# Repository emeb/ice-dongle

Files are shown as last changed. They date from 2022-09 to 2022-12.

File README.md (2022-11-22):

# ice-dongle
USB-C Dongle with ice40 UP5k FPGA

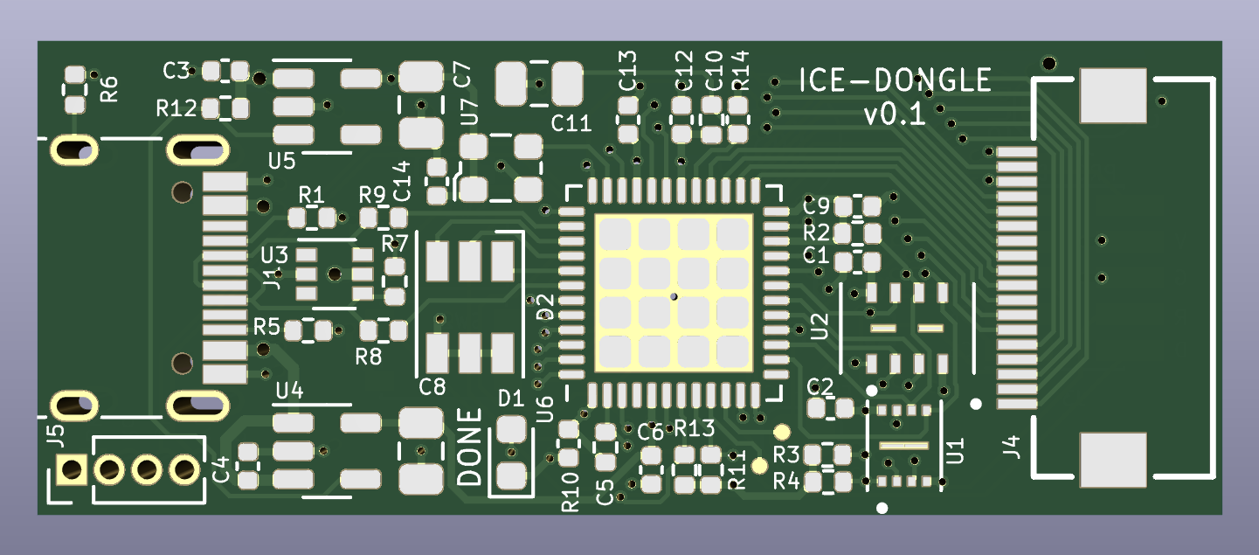
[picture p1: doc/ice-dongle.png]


## Abstract
This is a small USB connected FPGA board in a "dongle" form-factor. Note that
it's not a true dongle since it doesn't have a USB plug (USB-C plugs are not
practical for DIY assembly at the time this was designed) - instead it has a
USB-C jack and you can use an inexpensive M-M adapter to achieve dongle-like
function.

For I/O it provides an 18-pin FPC connector that conforms to the Eye-SPI
standard found on some Adafruit products. This standard includes 3.3V power
as well as 16 GPIO for things like SPI or I2C device, most often TFT LCD
displays and user interfaces.

The FPGA is directly connected to USB and is pinned-out similarly to the
1bitsquared Icebreaker Bitsy so the NO2FPGA bootloader and user designs for
that ecosystem should port over with minimal changes. It includes 8MB of flash
and 8MB of PSRAM, as well as an RGB LED and a user button.

Initial programming of the FPGA bitstream takes place through a 1.27mm SMD
header footprint on the back of the board. The original intent was to access
this temporarily via the Adafruit "Pogo Pin Probe Clip" which should have
attached easily over the pads. Unfortunately the pogo pin row spacing is too
narrow for the SMT header pads so I ended up soldering on a header and using
a normal cable. This may be fixed in future revisions, but for now an actual
header + cable is probably more reliable for long-term development.

## Status
### 22-10-15
Boards are back from OSHpark and so far things are working.
* USB power, regulators and clock oscillator are running properly.
  * Minor silkscreen error was discovered - reference designators for R14 and C10 swapped.
* FPGA configures via programming header and from SPI flash.
* SPI flash can be written from the programming header.
* RGB LED works.
* EYESPI bus works with ST7789 TFT LCD
* PSRAM works.

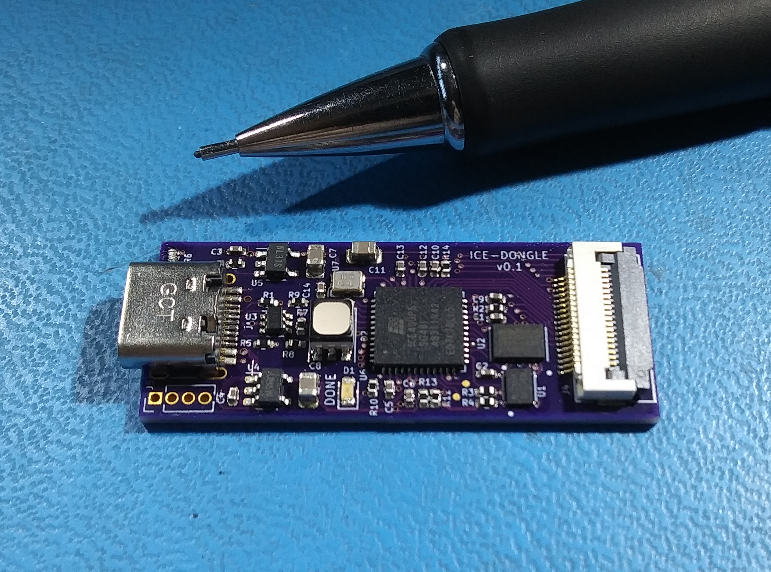
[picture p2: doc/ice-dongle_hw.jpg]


### 22-10-16
USB FS interface is fully functional with the NO2 Bootloader. I've forked it to
add a custom BOARD target for ice-dongle but I'll submit a PR to the main project
when things settle down a bit. For the time being here's my fork:

[NO2 Bootloader](https://github.com/emeb/no2bootloader)

To build, clone that and follow the directions in the README. A few additional
notes:
* Don't forget to `git submodule update --init` to get all the related material
from the NO2 ecosystem.
* To build use `make BOARD=ice-dongle bootloader`
* The `riscv_lcd` gateware project has a `make dfu` target that shows how to use
the bootloader.

### 22-10-17
Ordered some helper boards to make interfacing easier:
* ice-fpc-pmod
* ice-prog-adapt

find out more about them in the [Hardware](Hardware) directory.

### 22-11-20
* Sylvain Munaut (@tnt) has built up a couple ice-dongle boards and confirmed that
they work outside my lab. He did spot another silkscreen error - R10 and C5 reference
designators are swapped. This doesn't significantly affect the board operation but
should be corrected.
* Updated NO2 board definition to put serial pins on programming
header and sent a PR which has been accepted. You can now use the mainline
NO2 bootloader repo instead of my fork.
* Added a LiteX gateware design. This works but even a minimal demo uses > 80% of
the FPGA resources.

### 22-11-21
Corrected silkscreen errors and bumped revision to V0.1a

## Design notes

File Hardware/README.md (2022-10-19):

# ice-dongle Hardware
These are kicad projects for the ice-dongle board.

## ice-dongle
the main board design for the ice-dongle



## ice-fpc-pmod
a simple FPC to dual PMOD breakout board. Note that this can be
used for both FPC -> PMOD socket as well as PMOD pin header -> FPC just by
flipping the board upside down.



## ice-prog-adapt
breaks out the 10-pin 1.27mm IDC header to 2.54mm single-row
pins for connection to a programmer and UART.



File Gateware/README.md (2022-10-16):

# ice-dongle Gateware
These are various FPGA gateware projects for the ice-dongle board. Everything here
uses the open-source FPGA tools available here:

https://github.com/YosysHQ/oss-cad-suite-build

The RISC-V firmware build requires a `riscv-64-unknown-elf` toolchain. You can
use the one that's available from the SiFive github:

https://github.com/sifive/freedom-tools/releases

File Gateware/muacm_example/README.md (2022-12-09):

ICE-Dongle ACM + 6502 project
=============================

This project is a combination of Sylvain Munaut's Nitro μACM Example
with a small 65c02 CPU system. I'll be fleshing it out further but for
now it's just a processor, RAM, ROM, 8-bit GPIO and a serial port interface
to the muacm core.

The rest of this documentation is from the muacm repo...

Nitro μACM Example skeleton project
===================================

This project is a small skeleton example of using the Nitro μACM
as a pre-built module. You can use it as a base skeleton for your
own project.

Project infos:
--------------

This project tries to be fairly simple while still illustrating
the points that a user of the μACM module are likely to encounter.

It implements a simple data loopback through a FIFO that lives in
a clock domain distinct from the USB clock domain.

It just instanciates the `muacm` pre-built module, feeds the
required 48 MHz clock in and associated reset signal and wires
up the USB signals to the right pads.

The data interface is then "crossed" over using a pair of special
companion blocks `muacm_xclk` that can be used to cross the clock
domain boundary from the USB domain into any other clock domain
as required by the user application.

Nitro μACM core:
----------------

For details about the core itself and its interface, please
refer to the top level `README.md`.

If you're using the example binary distribution package, then
this should be available here as `README-core.md`.

Clocking Infos:
---------------

The μACM core itself is required to run at 48 MHz to operate
properly (USB is 12 MBits and we use 4x oversampling for clock
recovery).

In this project the 48 MHz clock can come from 2 sources depending
on the `HFOSC` define at the top of `top.v`:

 - Either it comes from the PLL where its generated appropriately
   depending on whatever crystal/oscillator is attached to the
   board (e.g. 48 MHz for the `fomu` or 12 MHz for the `bitsy`).
   The advantage of this approach is a high clock quality and
   precision, but it also uses the PLL which is a precious
   resource that might be needed to generate some other frequency
   in the design.
   In this particular design we generate both 48 MHz ("USB clock")
   and 24 MHz ("User clock") from the PLL but that might not be
   an option in your design.

 - The other option (only in `UP5k`) is to use the `SB_HFOSC`
   block which provides a 48 MHz internal oscillator.
   The advantage is that the PLL remains free and can be used
   to generate any frequency that the user needs.
   The downside is that technically the oscillator is not precise
   enough for the USB spec. I haven't seen any instances where this
   has causes any issue but YMMV.

The data interface out of the blocck is synchronous to the USB
clock. If you need to pass data back/forth a custom user clock
domain, it's recommended to make use of the companion blocks
`muacm_xclk` provided in this repo, or to use asynchronous FIFOs.

The `muacm_xclk` is not very performant but is still good enough
to not cause much penatly if a minimal amount of buffering is
provided on the user side.

Options:
--------

There are a few options that can be enabled / disabled with defines
at the beginning of `top.v` or by changing some `localparam` :

 - `WITH_FIFO`: Add a tiny FIFO in the loopback path, running in the
   user clock domain. This helps efficiency.

 - `WITH_BUTTON`: This makes uses of a small `dfu_helper.v` block
   that connects to the button on the board (if available) and
   it allows to manually reboot into the bootloader when executing
   a long press on the button.

 - `HFOSC`: See 'Clocking' section above.

 - `BOOT_IMAGE`: By default when receiving a `DFU_DETACH` request,
   this will reboot to `WARMBOOT` image `0b01` which is correct
   if you're using the `no2bootloader`. However if using `foboot`,
   it lives in image `0b00` and so that's what should be selected
   to trigger a reboot to `foboot`.

Build:
------

To build:

```
make BOARD=bitsy-v1
```

To program via DFU (assuming a DFU bootloader is already loaded):

```
make BOARD=bitsy-v1 prog
```

Supported boards:

  - `bitsy-v0`: iCEbreaker bitsy rev 0.x
  - `bitsy-v1`: iCEbreaker bitsy rev 1.x
  - `fomu-hacker`: FOMU hacker board
  - `fomu-pvt1`: FOMU production board
  - `tinyfpga-bx`: TinyFPGA-BX board

Make sure to run `make clean` between changing board configuration
since simply changing the `BOARD` variable will not trigger a rebuild.

Board specific notes
--------------------

### 1BitSquared iCEBreaker Bitsy

Those boards are probably the best supported and since they ship with
`no2bootloader` as the main way of loading firmware onto them will
integrate nicely with this project.

### FOMU using `fooboot`

`foboot` is a DFU bootloader so it integrates pretty well with the
DFU runtime provided by `muacm` if you set the `BOOT_IMAGE` to `0b00`
(which is the slot where `foboot` resides). Note that on power up
`foboot` always starts by default and you need to explicitely start
the user bitstream using `dfu-util -e`.

For the `fomu`, since there is no physical button, what is used is
the IO pad 1 and can be 'pressed' by shorting it to ground (for instance
by using tweezers).

### FOMU using `no2bootloader`

If you have replaced the bootloader on your FOMU with `no2bootloader`
instead, then the notes above regarding the `BOOT_IMAGE` settings don't
apply.

### TinyFPGA-BX

This board is using the `iCE40 LP8k` and as such doesn't have an internal
48 MHz oscillator. You must make sure the `HFOSC` option is not selected.

Also, the only button present on this board is directly wired to the
fpga reset pin and is not accessible to the user, so the `WITH_BUTTON`
must also be disabled.

The default bootloader that ships from the vendor with this board is
the _TinyFPGA-Bootloader_ which is not a DFU bootloader. `muacm` will
still expose a DFU runtime interface and you can use `dfu-util -e` to
programmatically reset the board back to the bootloader if you
properly set `BOOT_IMAGE` to `0b00` but you will need to use `tinyprog`
to actually flash a bitstream.

Finally, the _TinyFPGA-Bootloader_ always boots first when plugging
the board into a USB port and will only boot the user bitstream if
either a new bitstream was just programmed, or by using `tinyprog -b`.
Refer to the board manual for more information about its bootloader
operations.

License
-------

 Everything included here is under permissive licenses.

 - The example verilog is under CERN-OHL-P-2.0

 - The bundled pre-built μACM core is a mix between CERN-OHL-P-2.0 and
   ISC (the latter being for the included SERV core). It also contains
   a firmware licensed under MIT.

 All the details can be found in the Nitro μACM git repository
 ( https://github.com/no2fpga/no2muacm ) but from a practical user stand
 point, the only thing required when using this core is attribution to :

 - Nitro FPGA project ( Sylvain Munaut - https://github.com/no2fpga/ )
 - SERV ( Olof Kindgren - https://github.com/olofk/serv )

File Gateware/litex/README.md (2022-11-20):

# ice-dongle LiteX
This builds a minimal LiteX bare-metal demo.

## Building and installing
Install Litex - go here for instructions:
[Litex Github](https://github.com/enjoy-digital/litex)

Put the ice-dongle in DFU mode:
* Press and hold `Boot` button.
* Press and release `RST` button.
* Release `Boot` button.

The RGB LED should by beating a slow cyan color indicating that the DFU
bootloader is ready.

Run the build script
```
./ice-dongle.py --build --flash
```
This will run for a few minutes to build and flash the LiteX demo design onto the
ice-dongle. After it completes you should be able to start up a serial terminal
and communicate with the LiteX command line. Try typing `help` to get started.

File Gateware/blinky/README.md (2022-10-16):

# ice-dongle Blinky
This is a simple RGB LED driver that's used to test the device immediately after
assembly just to make sure basic stuff is working.

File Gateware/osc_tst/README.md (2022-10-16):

# ice-dongle osc_tst
This is a quick test to check out the operation of the on-board 12MHz oscillator
and the FPGA on-chip PLL.

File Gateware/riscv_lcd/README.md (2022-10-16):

# ice-dongle riscv_lcd
This is a RISC-V system with UART, 2 x SPI and I2C used to check out the EYE-SPI
bus and test the SPI PSRAM and Flash interfaces.

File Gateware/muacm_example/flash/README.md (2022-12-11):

Flash data
==========
This directory contains the raw 8KB BASIC ROM contents that is written at
location 0xA0000 in the SPI Flash memory and loaded into SPRAM at run time.

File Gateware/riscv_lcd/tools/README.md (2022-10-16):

#riscv_lcd tools
This directory contains ancillary tools used to generate image data that is
loaded into the SPI flash for display on the LCD.

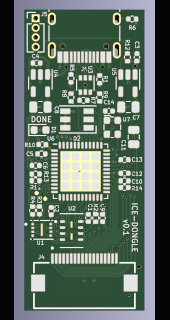
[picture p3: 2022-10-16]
Gateware/riscv_lcd/tools/ice-dongle_clip.png

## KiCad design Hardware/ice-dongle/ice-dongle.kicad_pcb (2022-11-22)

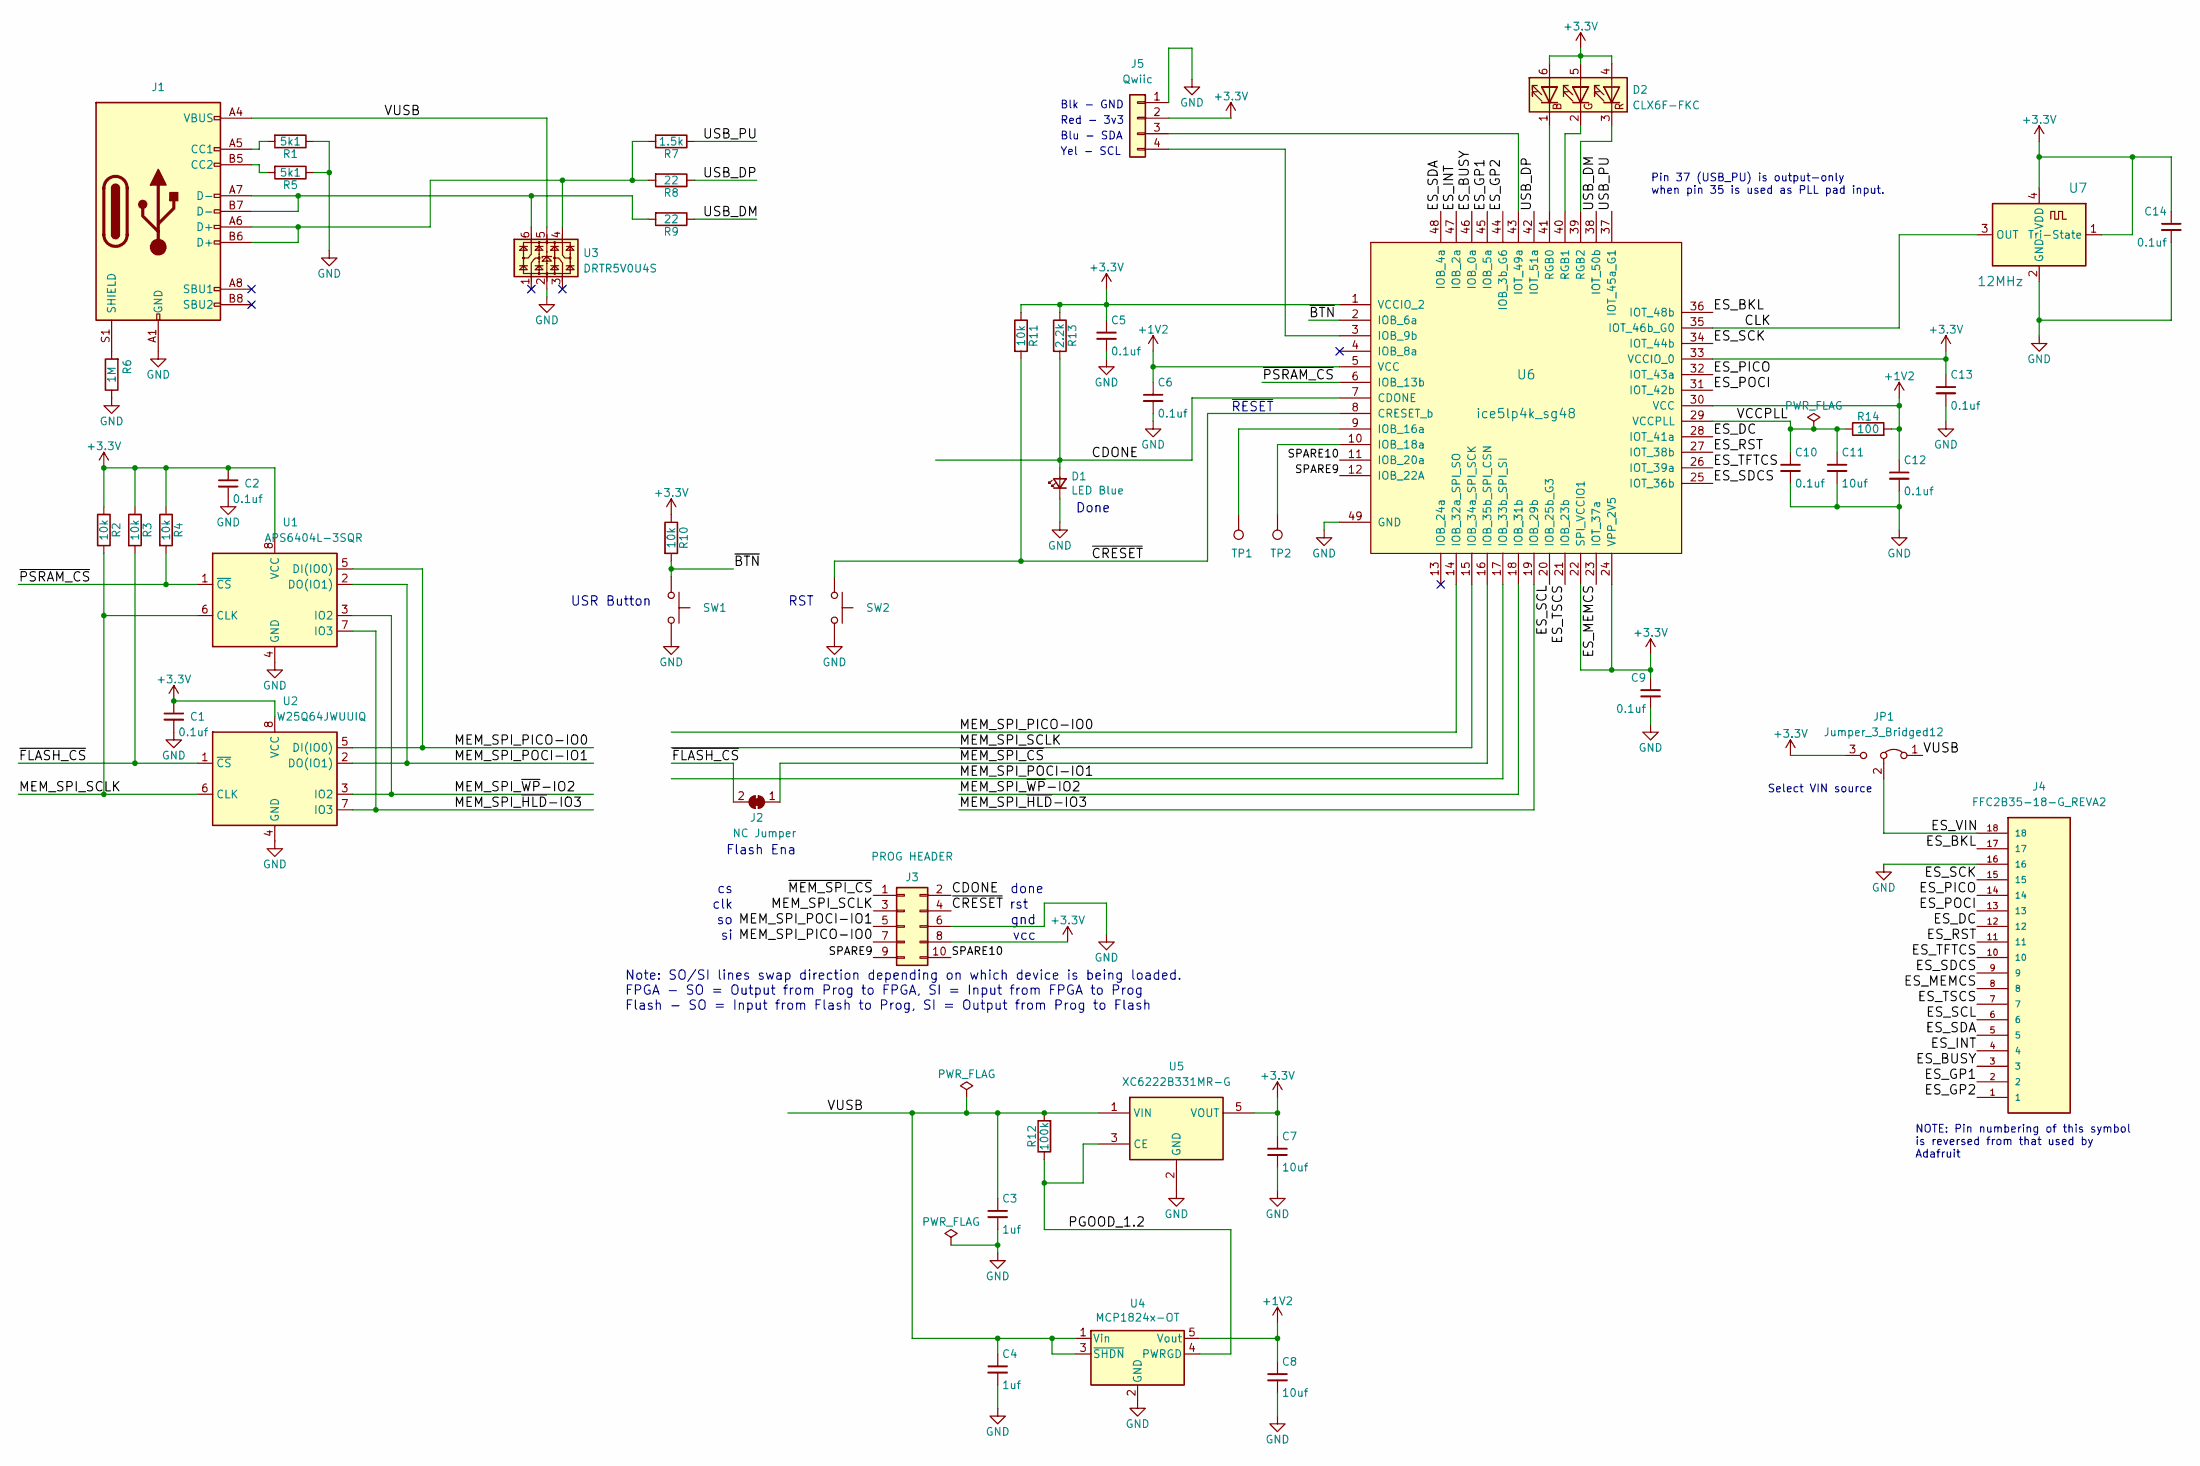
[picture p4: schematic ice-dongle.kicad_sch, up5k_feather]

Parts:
C1, C2, C5, C6, C9, C10, C12, C13, C14: 0.1uf; C_0402_1005Metric
C3, C4: 1uf; C_0402_1005Metric
C7, C8, C11: 10uf; C_0805_2012Metric
D1: LED Blue; LED_0603_1608Metric
D2: CLX6F-FKC; LED_RGB_PLCC-6
J1: USB_C_Receptacle_USB2.0; USB_C_Receptacle_HRO_TYPE-C-31-M-12
J2: NC Jumper; SolderJumper-2_P1.3mm_Bridged_RoundedPad1.0x1.5mm
J3: PROG HEADER; PinHeader_2x05_P1.27mm_Vertical_SMD
J4: FFC2B35-18-G_REVA2; GCT_FFC2B35-18-G_REVA2; PARTREV A2
J5: Qwiic; PinHeader_1x04_P1.27mm_Vertical
JP1: Jumper_3_Bridged12; SolderJumper-3_P1.3mm_Bridged12_RoundedPad1.0x1.5mm
R1, R5: 5k1; R_0402_1005Metric
R2, R3, R4, R10, R11: 10k; R_0402_1005Metric
R6: 1M; R_0402_1005Metric
R7: 1.5k; R_0402_1005Metric
R8, R9: 22; R_0402_1005Metric
R12: 100k; R_0402_1005Metric
R13: 2.2k; R_0402_1005Metric
R14: 100; R_0402_1005Metric
SW1, SW2: SW_Push; SW_SPST_PTS815
TP1, TP2: TestPoint; TestPoint_Pad_D0.5mm
U1: APS6404L-3SQR; USON-8_2x3
U2: W25Q64JWUUIQ; USON-8_4x3
U3: DRTR5V0U4S; SOT-363_SC-70-6
U4: MCP1824x-OT; SOT-23-5
U5: XC6222B331MR-G; SOT-23-5
U6: ice5lp4k_sg48; QFN-48-1EP_7x7mm_P0.5mm_EP5.3x5.3mm
U7: 12MHz; Oscillator_SMD_ECS_2520MV-xxx-xx-4Pin_2.5x2.0mm

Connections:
+1V2: C6.1, C8.1, C12.1, R14.2, U4.5 (Vout), U6.5 (VCC), U6.30 (VCC)
+3.3V: C1.1, C2.1, C5.1, C7.1, C9.1, C13.1, C14.1, D2.4 (BA), D2.5 (GA), D2.6 (RA), J3.8, J5.2, JP1.3 (B), R2.1, R3.1, R4.1, R10.1, R11.1, R13.1, U1.8 (VCC), U2.8 (VCC), U5.5 (VOUT), U6.1 (VCCIO_2), U6.22 (SPI_VCCIO1), U6.24 (VPP_2V5), U6.33 (VCCIO_0), U7.1 (Tri-State), U7.4 (VDD)
/CDONE: D1.2 (A), J3.2, R13.2, U6.7 (CDONE)
/CLK: U6.35 (IOT_46b_G0), U7.3 (OUT)
/ES_BKL: J4.17, U6.36 (IOT_48b)
/ES_BUSY: J4.3, U6.46 (IOB_0a)
/ES_DC: J4.12, U6.28 (IOT_41a)
/ES_GP1: J4.2, U6.45 (IOB_5a)
/ES_GP2: J4.1, U6.44 (IOB_3b_G6)
/ES_INT: J4.4, U6.47 (IOB_2a)
/ES_MEMCS: J4.8, U6.23 (IOT_37a)
/ES_PICO: J4.14, U6.32 (IOT_43a)
/ES_POCI: J4.13, U6.31 (IOT_42b)
/ES_RST: J4.11, U6.27 (IOT_38b)
/ES_SCK: J4.15, U6.34 (IOT_44b)
/ES_SCL: J4.6, U6.20 (IOB_25b_G3)
/ES_SDA: J4.5, U6.48 (IOB_4a)
/ES_SDCS: J4.9, U6.25 (IOT_36b)
/ES_TFTCS: J4.10, U6.26 (IOT_39a)
/ES_TSCS: J4.7, U6.21 (IOB_23b)
/ES_VIN: J4.18, JP1.2 (C)
/MEM_SPI_PICO-IO0: J3.7, U1.5 (DI(IO0)), U2.5 (DI(IO0)), U6.14 (IOB_32a_SPI_SO)
/MEM_SPI_POCI-IO1: J3.5, U1.2 (DO(IO1)), U2.2 (DO(IO1)), U6.17 (IOB_33b_SPI_SI)
/MEM_SPI_SCLK: J3.3, R2.2, U1.6 (CLK), U2.6 (CLK), U6.15 (IOB_34a_SPI_SCK)
/MEM_SPI_~HLD-IO3: U1.7 (IO3), U2.7 (IO3), U6.19 (IOB_29b)
/MEM_SPI_~WP-IO2: U1.3 (IO2), U2.3 (IO2), U6.18 (IOB_31b)
/PGOOD_1.2: R12.1, U4.4 (PWRGD), U5.3 (CE)
/SPARE9: J3.9, U6.12 (IOB_22A)
/SPARE10: J3.10, U6.11 (IOB_20a)
/USB_DM: R9.1, U6.38 (IOT_50b)
/USB_DP: R8.1, U6.42 (IOT_51a)
/USB_PU: R7.1, U6.37 (IOT_45a_G1)
/VCCPLL: C10.1, C11.1, R14.1, U6.29 (VCCPLL)
/VUSB: C3.1, C4.1, J1.A4 (VBUS), J1.A9 (VBUS), J1.B4 (VBUS), J1.B9 (VBUS), JP1.1 (A), R12.2, U3.5, U4.1 (Vin), U4.3 (~SHDN), U5.1 (VIN)
/~BTN: R10.2, SW1.1, U6.2 (IOB_6a)
/~CRESET: J3.4, R11.2, SW2.1, U6.8 (CRESET_b)
/~FLASH_CS: J2.2 (B), R3.2, U2.1 (~CS)
/~MEM_SPI_CS: J2.1 (A), J3.1, U6.16 (IOB_35b_SPI_CSN)
/~PSRAM_CS: R4.2, U1.1 (~CS), U6.6 (IOB_13b)
GND: C1.2, C2.2, C3.2, C4.2, C5.2, C6.2, C7.2, C8.2, C9.2, C10.2, C11.2, C12.2, C13.2, C14.2, D1.1 (K), J1.A1 (GND), J1.A12 (GND), J1.B1 (GND), J1.B12 (GND), J3.6, J4.16, J5.1, R1.1, R5.1, R6.1, SW1.2, SW2.2, U1.4 (GND), U2.4 (GND), U3.2, U4.2 (GND), U5.2 (GND), U6.49 (GND), U7.2 (GND)
unnamed: D2.1 (RK), U6.41 (RGB0)
unnamed: D2.2 (GK), U6.40 (RGB1)
unnamed: D2.3 (BK), U6.39 (RGB2)
unnamed: J1.A5 (CC1), R1.2
unnamed: J1.A6 (D+), J1.B6 (D+), R7.2, R8.2, U3.4
unnamed: J1.A7 (D-), J1.B7 (D-), R9.2, U3.6
unnamed: J1.B5 (CC2), R5.2
unnamed: J1.S1 (SHIELD), R6.2
unnamed: J5.3, U6.43 (IOT_49a)
unnamed: J5.4, U6.3 (IOB_9b)
unnamed: TP1.1, U6.9 (IOB_16a)
unnamed: TP2.1, U6.10 (IOB_18a)

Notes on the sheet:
vcc
done
Yel - SCL
RST
Blk - GND
USR Button
Red - 3v3
Note: SO/SI lines swap direction depending on which device is being loaded. FPGA - SO = Output from Prog to FPGA, SI = Input from FPGA to Prog Flash - SO = Input from Flash to Prog, SI = Output from Prog to Flash
Done
gnd
Flash Ena
clk
Pin 37 (USB_PU) is output-only when pin 35 is used as PLL pad input.
NOTE: Pin numbering of this symbol is reversed from that used by Adafruit
Blu - SDA
rst
~{RESET}
Select VIN source

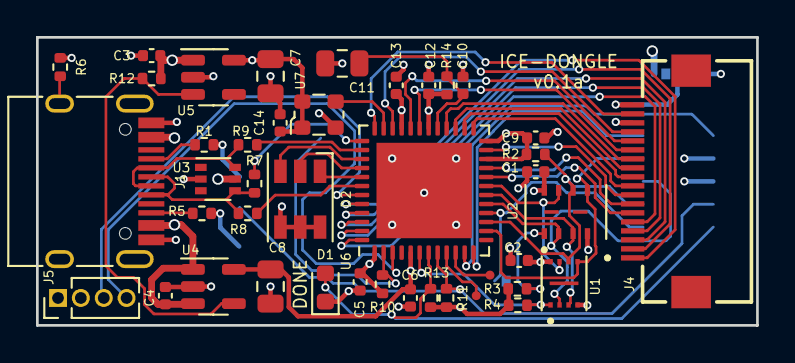
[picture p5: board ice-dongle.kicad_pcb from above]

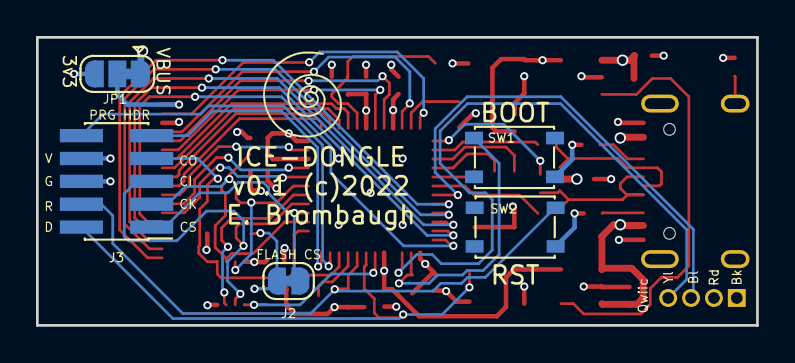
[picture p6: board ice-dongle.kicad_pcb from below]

Board: 4 copper layers, 40.0 x 16.0 mm, 48 parts (6 on the bottom side), 52 nets.

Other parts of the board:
Ref**: Val**; avatar_small

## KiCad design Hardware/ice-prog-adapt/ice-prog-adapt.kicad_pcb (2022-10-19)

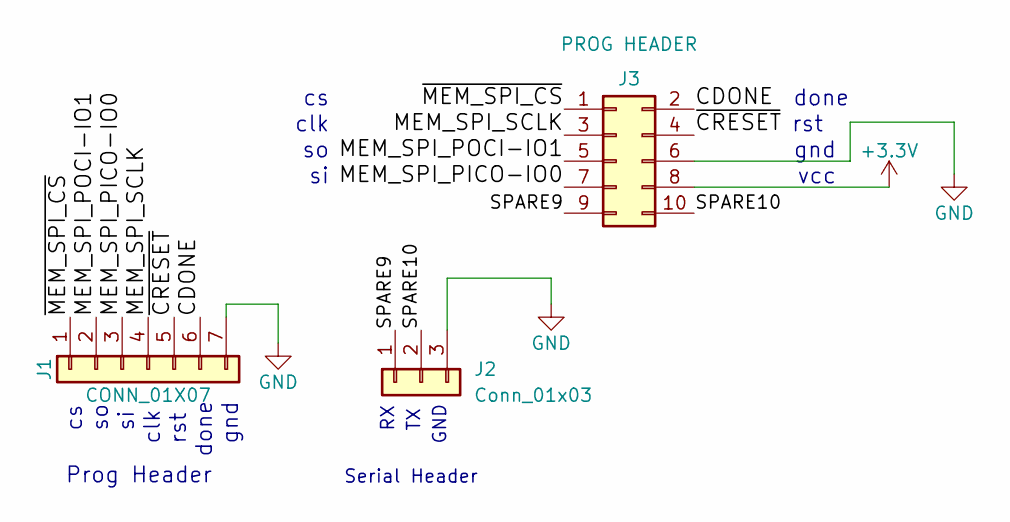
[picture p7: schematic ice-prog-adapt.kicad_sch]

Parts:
J1: CONN_01X07; PinHeader_1x07_P2.54mm_Vertical
J2: Conn_01x03; PinHeader_1x03_P2.54mm_Vertical
J3: PROG HEADER; PinHeader_2x05_P1.27mm_Vertical_SMD

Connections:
+3.3V: J3.8
/CDONE: J1.6, J3.2
/MEM_SPI_PICO-IO0: J1.3, J3.7
/MEM_SPI_POCI-IO1: J1.2, J3.5
/MEM_SPI_SCLK: J1.4, J3.3
/SPARE9: J2.1, J3.9
/SPARE10: J2.2, J3.10
/~CRESET: J1.5, J3.4
/~MEM_SPI_CS: J1.1, J3.1
GND: J1.7, J2.3, J3.6

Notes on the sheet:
GND
Serial Header
vcc
gnd
clk
done
rst
Prog Header

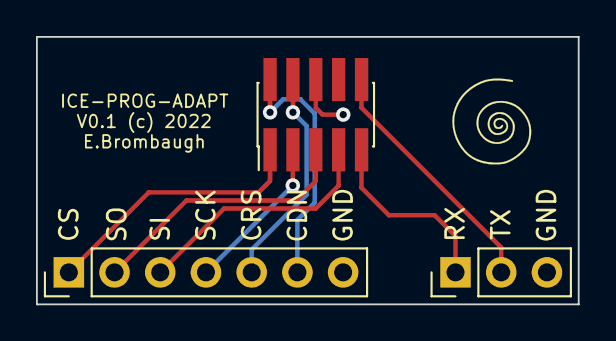
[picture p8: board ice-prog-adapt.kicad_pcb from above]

Board: 2 copper layers, 30.1 x 14.9 mm, 4 parts (0 on the bottom side), 9 nets.

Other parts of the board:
Ref**: Val**; avatar_small

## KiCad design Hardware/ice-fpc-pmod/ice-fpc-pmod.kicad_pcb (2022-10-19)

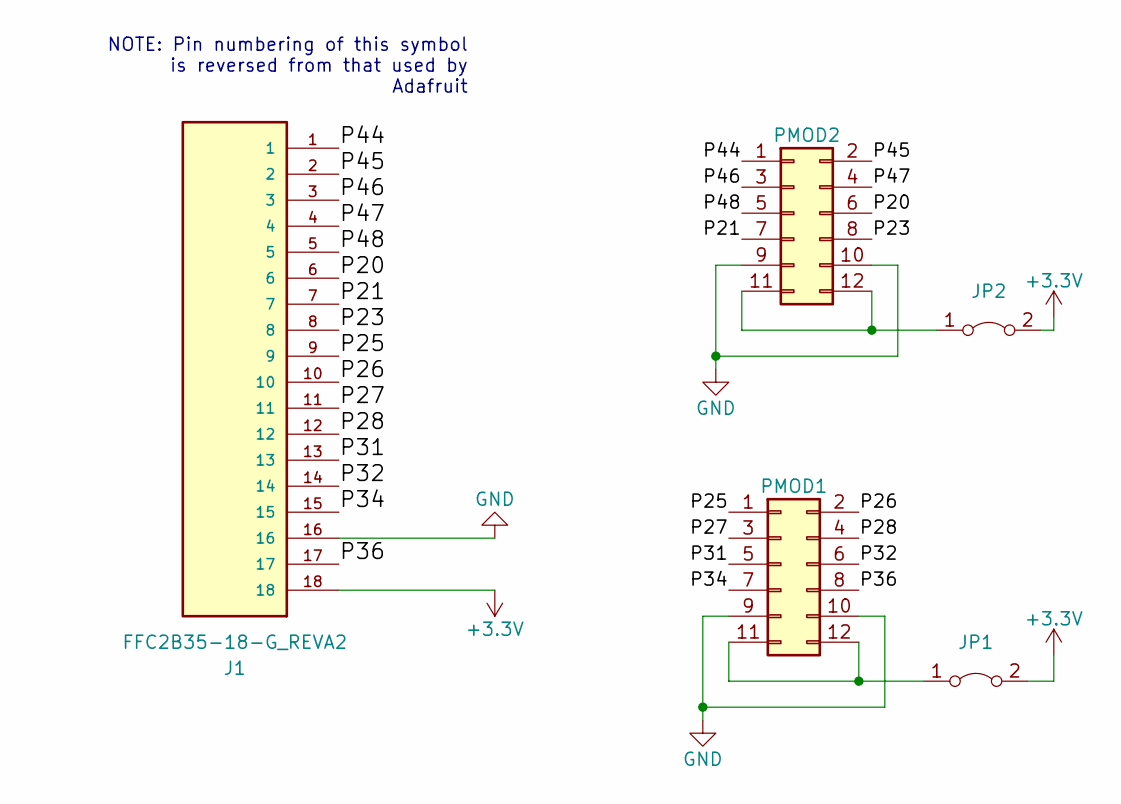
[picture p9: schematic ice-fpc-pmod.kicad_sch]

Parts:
J1: FFC2B35-18-G_REVA2; GCT_FFC2B35-18-G_REVA2; PARTREV A2
JP1, JP2: Jumper_2_Bridged; SolderJumper-2_P1.3mm_Bridged_RoundedPad1.0x1.5mm
PMOD1, PMOD2: CONN_02X06; PinSocket_2x06_P2.54mm_Vertical

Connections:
+3.3V: J1.18, JP1.2 (B), JP2.2 (B)
/P20: J1.6, PMOD2.6
/P21: J1.7, PMOD2.7
/P23: J1.8, PMOD2.8
/P25: J1.9, PMOD1.1
/P26: J1.10, PMOD1.2
/P27: J1.11, PMOD1.3
/P28: J1.12, PMOD1.4
/P31: J1.13, PMOD1.5
/P32: J1.14, PMOD1.6
/P34: J1.15, PMOD1.7
/P36: J1.17, PMOD1.8
/P44: J1.1, PMOD2.1
/P45: J1.2, PMOD2.2
/P46: J1.3, PMOD2.3
/P47: J1.4, PMOD2.4
/P48: J1.5, PMOD2.5
GND: J1.16, PMOD1.9, PMOD1.10, PMOD2.9, PMOD2.10
unnamed: JP1.1 (A), PMOD1.11, PMOD1.12
unnamed: JP2.1 (A), PMOD2.11, PMOD2.12

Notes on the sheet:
NOTE: Pin numbering of this symbol is reversed from that used by Adafruit

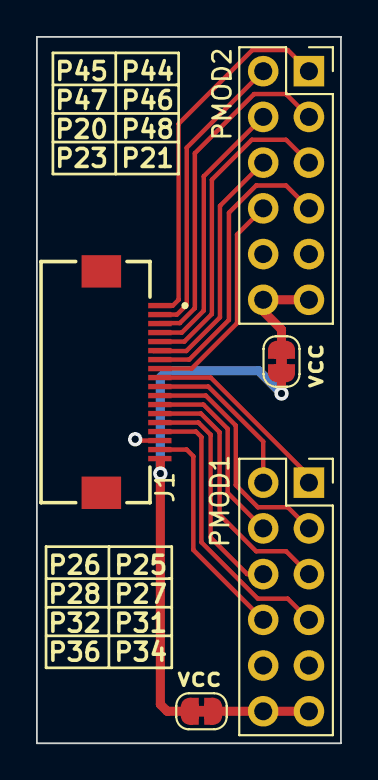
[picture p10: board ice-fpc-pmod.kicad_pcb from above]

Board: 2 copper layers, 16.9 x 39.2 mm, 6 parts (1 on the bottom side), 20 nets.

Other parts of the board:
Ref**: Val**; avatar_small

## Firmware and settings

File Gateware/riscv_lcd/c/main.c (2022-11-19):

/*
 * main.c - top level of picorv32 firmware
 * 06-30-19 E. Brombaugh
 */

#include <stdio.h>
#include "riscv_lcd.h"
#include "acia.h"
#include "printf.h"
#include "spi.h"
#include "flash.h"
#include "psram.h"
#include "clkcnt.h"
#include "st7789.h"
#include "i2c.h"
#include "cmd.h"

/* build time */
const char *bdate = __DATE__;
const char *btime = __TIME__;
const char *fwVersionStr = "V0.1";

/*
 * simple text output to graphics
 */
uint8_t gline = 0;
static void putcp(void* p,char c)
{
    *(*((char**)p))++ = c;
}
void gprintf(char *fmt, ...)
{
	char s[32], *h = s;
    va_list va;
    va_start(va,fmt);
    tfp_format(&h,putcp,fmt,va);
    putcp(&h,0);
    va_end(va);
	st7789_drawstr(0, 8*gline++, s, ST7789_WHITE, ST7789_BLACK);
}

/*
 * main
 */
void main()
{
	uint32_t cnt, spi_id, i, j;
	char gbuf[32];
	//int c;
	
	init_printf(0, acia_printf_putc);
	printf("\n\n\r-----------------------------\n\r");
	printf("riscv_lcd - starting up\n\r");
    printf("Version: %s\n\r", fwVersionStr);
    printf("Build Date: %s\n\r", bdate);
    printf("Build Time: %s\n\r", btime);
	printf("-----------------------------\n\r");

	/* test both SPI ports */
	spi_init(SPI0);
	spi_init(SPI1);
	
#if 1
	/* Init LCD */
	st7789_init(SPI1);
	printf("LCD initialized\n\r");
#endif

#if 0
	/* test lcd text */
	for(i=0;i<40;i++)
	{
		gprintf("Line %d", i);
	}
#endif

#if 0
	/* get spi flash id */
	flash_init(SPI0);	// wake up the flash chip
	spi_id = flash_id(SPI0);
	printf("spi flash id: 0x%08X\n\r", spi_id);
	gprintf("SPI Flash Test...");
	gprintf("ID: 0x%08X", spi_id);
	
	/* read some data */
	{
		uint8_t read[128];
		flash_read(SPI0, read, 0x200000, 128);
		for(i=0;i<128;i+=4)
		{
			gprintf("%02X: %02X %02X %02X %02X", i, read[i], read[i+1], read[i+2], read[i+3] );
		}
	}
#endif

#if 0
	/* get spi psram id */
	spi_id = psram_id(SPI0);
	printf("spi psram id: 0x%08X\n\r", spi_id);
	gprintf("SPI PSRAM Test...");
	gprintf("ID: 0x%08X", spi_id);
	
	/* read some data */
	{
		uint8_t read[128];
		psram_read(SPI0, read, 0, 128);
		gprintf("read");
		for(i=0;i<16;i+=4)
		{
			gprintf("%02X: %02X %02X %02X %02X", i, read[i], read[i+1], read[i+2], read[i+3] );
		}
		
		gprintf("write");
		for(i=0;i<16;i++)
			read[i] = i<<4 | 0xf;
		for(i=0;i<16;i+=4)
		{
			gprintf("%02X: %02X %02X %02X %02X", i, read[i], read[i+1], read[i+2], read[i+3] );
		}
		psram_write(SPI0, read, 0, 128);
		
		gprintf("zero");
		for(i=0;i<16;i++)
			read[i] = 0;
		for(i=0;i<16;i+=4)
		{
			gprintf("%02X: %02X %02X %02X %02X", i, read[i], read[i+1], read[i+2], read[i+3] );
		}
		
		psram_read(SPI0, read, 0, 128);
		gprintf("re-read");
		for(i=0;i<16;i+=4)
		{
			gprintf("%02X: %02X %02X %02X %02X", i, read[i], read[i+1], read[i+2], read[i+3] );
		}
	}
#endif

#if 0
	/* test limits */
	st7789_fillScreen(ST7789_BLACK);
#define XMIN 0
#define XMAX st7789_width()
#define YMIN 0
#define YMAX st7789_height()
	st7789_drawFastVLine(XMIN, YMIN, YMAX, ST7789_WHITE);
	st7789_drawFastVLine(XMAX-1, YMIN, YMAX, ST7789_WHITE);
	st7789_drawFastHLine(XMIN, YMIN, XMAX-XMIN, ST7789_WHITE);
	st7789_drawFastHLine(XMIN, YMAX-1, XMAX-XMIN, ST7789_WHITE);
	st7789_drawLine(XMIN, YMIN, XMAX, YMAX, ST7789_WHITE);
	st7789_drawLine(XMAX, YMIN, XMIN, YMAX, ST7789_WHITE);
	//st7789_drawstr(XMAX/2-44, (YMAX/2-4), "Hello World",
	//	ST7789_WHITE, ST7789_BLACK);
#endif
	
#if 1
	/* color fill + text fonts */
	printf("Color Fill & Fonts\n\r");
	st7789_fillScreen(ST7789_MAGENTA);
	st7789_drawstr(st7789_width()/2-44, (st7789_height()/2-12*8), "Hello World", ST7789_WHITE, ST7789_MAGENTA);
	
	/* test font */
	for(i=0;i<256;i+=16)
		for(j=0;j<16;j++)
			st7789_drawchar((st7789_width()/2-8*8)+(j*8), (st7789_height()/2-8*8)+(i/2), i+j,
				ST7789_GREEN, ST7789_BLACK);
	
	clkcnt_delayms(1000);
#endif
	
#if 0
	/* test colored lines */
	printf("Colored Lines\n\r");
	{
		uint8_t rgb[3], hsv[3];
		uint16_t color;
		st7789_fillScreen(ST7789_BLACK);
		hsv[1] = 255;
		hsv[2] = 255;
		j=256;
		while(j--)
		{	
			for(i=0;i<st7789_width();i++)
			{
				hsv[0] = (i+j);
				
				st7789_hsv2rgb(rgb, hsv);
				color = st7789_Color565(rgb[0],rgb[1],rgb[2]);
		#if 1
				/* rotating box */
				st7789_drawLine(i, 0, st7789_width()-1, i, color);
				st7789_drawLine(st7789_width()-1, i, st7789_width()-1-i, st7789_width()-1, color);
				st7789_drawLine(st7789_width()-1-i, st7789_width()-1, 0, st7789_width()-1-i, color);
				st7789_drawLine(0, st7789_width()-1-i, i, 0, color);
		#else
				/* slow downward motion */
				st7789_drawFastHLine(0, i, st7789_width(), color);
		#endif
			}
		}
	}
	clkcnt_delayms(1000);
#endif

#if 1
	/* test image blit from flash */
	{
		flash_init(SPI0);	// wake up the flash chip
		uint16_t blit[ST7789_TFTWIDTH*4];
		uint32_t blitaddr, blitsz;
		blitaddr = 0xa0000;
		blitsz = ST7789_TFTWIDTH*4*sizeof(uint16_t);
		for(i=0;i<ST7789_TFTHEIGHT;i+=4)
		{
			flash_read(SPI0, (uint8_t *)blit, blitaddr, blitsz);
			st7789_blit(0, i, ST7789_TFTWIDTH, 4, blit);
			blitaddr += blitsz;
		}
	}
#endif

	/* Test I2C */
	//i2c_init(I2C0);
	//printf("I2C0 Initialized\n\r");
	
#if 0
	/* command interp */
	printf("Command Interp\n\r");
	cmd_init();
#endif
	
	cnt = 0;
	//printf("Looping...\n\r");
	clkcnt_reg = 0;
	while(1)
	{
		/* blink LED @ 200ms rate */
		if(clkcnt_reg > (24000*200))
		{
			gp_out = (gp_out&~(7<<17))|((cnt&7)<<17);
			clkcnt_reg = 0;
		}
		
#if 0
		/* master transmit test */
		if(i2c_mtx(I2C0, 0x1A, (uint8_t *)&cnt, 2))
			acia_putc('x');
		else
			acia_putc('.');
#endif

#if 0
		/* slave receive (blocking) test */
		{
			uint16_t data;
			if(i2c_srx(I2C0, 0x19, (uint8_t *)&data, 2)&1)
			{
				printf("----\n\r");
			}
			else
			{
				printf("0x%04X\n\r", data);
			}
		}
#endif
		
		cnt++;
		
#if 1
		/* simple echo */
		int c=acia_getc();
		if(c != EOF)
			acia_putc(c);
#endif
#if 0
		/* command processing */
		cmd_proc();
#endif
	}
}

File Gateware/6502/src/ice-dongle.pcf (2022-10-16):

######################
# ice-dongle pinout
######################

# Boot Button
set_io BTN 2

# StemmaQT / QWIIC 
set_io QWIIC_SCL 3
set_io QWIIC_SDA 43

# Spares on Programming Header
set_io SPARE9 12
set_io SPARE10 11

# testpoints
set_io TP1 9
set_io TP2 10

# NC pins
set_io NC4 4
set_io NC13 13

# SPI Memory interface
set_io MEM_SPI_PICO_IO0 14
set_io MEM_SPI_POCI_IO1 17
set_io MEM_SPI_SCLK 15
set_io MEM_SPI_CS 16
set_io MEM_SPI_WP_IO2 18
set_io MEM_SPI_HLD_IO3 19
set_io PSRAM_CS 6

# Eye-SPI connector
set_io ES_BKL 36
set_io ES_SCK 34
set_io ES_PICO 32
set_io ES_POCI 31
set_io ES_DC 28
set_io ES_RST 27
set_io ES_TFTCS 26
set_io ES_SDCS 25
set_io ES_MEMCS 23
set_io ES_TSCS 21
set_io ES_SCL 20
set_io ES_SDA 48
set_io ES_INT 47
set_io ES_BUSY 46
set_io ES_GP1 45
set_io ES_GP2 44

# USB
set_io USB_DP 42
set_io USB_DM 38
set_io USB_PU 37

# 12MHz Clock Oscillator
set_io CLK12MHZ 35

# RGB LED
set_io RGB0 39
set_io RGB1 40
set_io RGB2 41

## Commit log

2022-09-21 Initial commit of ice-dongle project
    [ice-dongle.kicad_pcb, ice-dongle.kicad_sch]
2022-09-25 USB-C jack, finish layout
    [ice-dongle.kicad_pcb, ice-dongle.kicad_sch]
2022-09-25 Fix Eye-SPI pinout, add VIN selector
    [ice-dongle.kicad_pcb, ice-dongle.kicad_sch]
2022-09-25 Fix issues pointed out by @m_w, update image
    [ice-dongle.kicad_pcb]
2022-09-25 Clean up USB & RGB routing.
    [ice-dongle.kicad_pcb, ice-dongle.kicad_sch]
2022-09-26 Minor cleanups, add unmarked testpoints to unused IO
    [ice-dongle.kicad_pcb, ice-dongle.kicad_sch]
2022-10-16 Updated w/ new status
    [ice-dongle.kicad_pcb, ice-dongle.kicad_sch]
2022-10-16 Added image display from SPI flash
2022-10-17 LED dimming, put image into DFU region 1
2022-10-19 Added some supporting board designs
    [ice-dongle.kicad_pcb, ice-dongle.kicad_sch, ice-fpc-pmod.kicad_pcb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]
2022-11-12 Serial echo and non-blocking LED timing
2022-11-22 Corrected swapped silkscreen refdes, bumped version to 0.1a
    [ice-dongle.kicad_pcb]
2022-11-22 Updated README for PCB fixes.
2022-12-07 Adding 6502 project
    [sbc.cfg]
2022-12-10 Added 6502 ROM building
    [sbc.cfg]
2022-12-10 Added 52kB SPRAM and rearranged I/O to support BASIC
    [sbc.cfg]
2022-12-10 Added SPI port for reading flash
2022-12-11 MS BASIC works now
    [sbc.cfg]
2023-03-08 Added microsecond timer and fixed USB RX interlock
2023-03-09 Use latest oss cad suite, fix load/save address to prevent damaging bootloader

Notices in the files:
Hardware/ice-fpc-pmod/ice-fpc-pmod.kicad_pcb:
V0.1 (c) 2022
